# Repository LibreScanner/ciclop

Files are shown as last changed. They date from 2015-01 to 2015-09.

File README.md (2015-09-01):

# Ciclop

In this repository you will find the source files for the [bq Ciclop 3D scanner](http://diwo.bq.com/en/tag/ciclop) [[es](http://diwo.bq.com/tag/ciclop)]. Also in [thingiverse](http://www.thingiverse.com/thing:740357). If you are missing something, please do not hesitate to [file an issue on github](https://github.com/bqlabs/ciclop/issues).

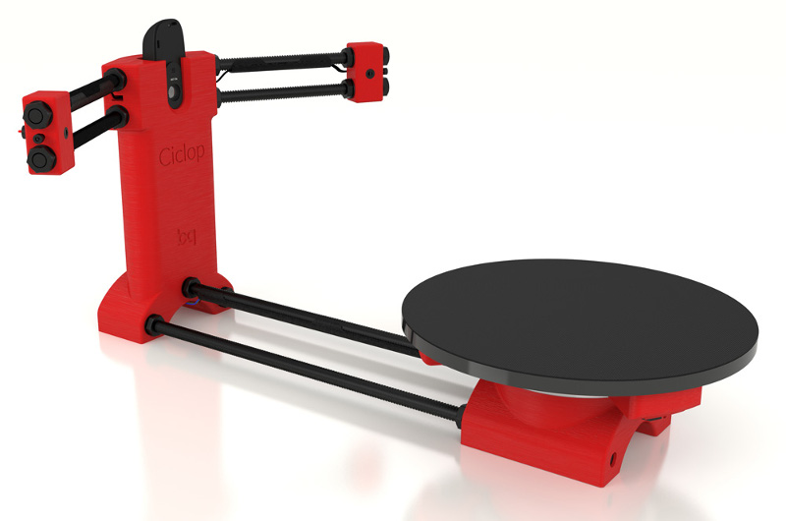
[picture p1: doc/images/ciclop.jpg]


Ciclop may be controlled by Horus software. You can find here the [firmware](https://github.com/bqlabs/horus-fw) and the [desktop application](https://github.com/bqlabs/horus).

## License 

Ciclop is licensed under a [Creative Commons Attribution-ShareAlike 4.0 International License](http://creativecommons.org/licenses/by-sa/4.0/)

Please read the LICENSE file for more details.

## Directory structure

 * `step`: The original Ciclop step files. This folder is frozen. Find the latest version in the `freecad` folder

 * `stl`: Ciclop STL files. It also contains parts with support for 3D printing

 * `dxf`: Ciclop DXF files. It contains all methacrylate pieces cutted with laser

 * `svg`: Ciclop SVG files. This folder contains all drawings for 2D printing

 * `freecad`: Ciclop source files in [FreeCAD](http://www.freecadweb.org/). This is a work in progress. All the original files are being migrated to Freecad (see below)

 * `Ciclop-BOM.ods`: Ciclop Bill of Materials. Document for [LibreOffice](https://www.libreoffice.org/)

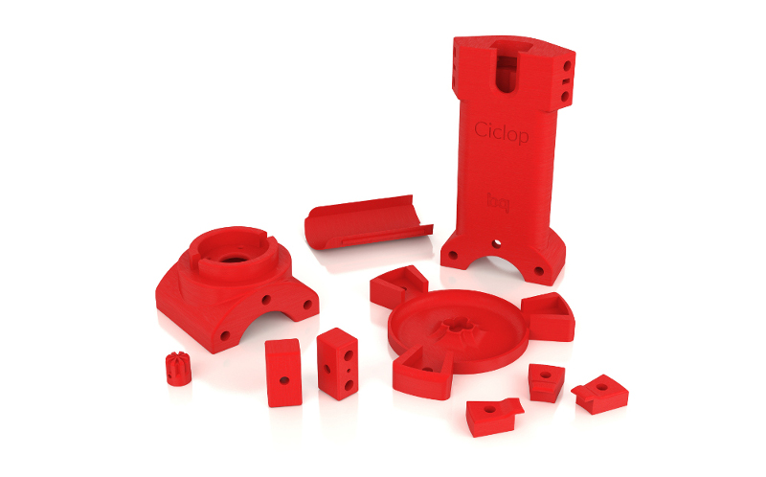
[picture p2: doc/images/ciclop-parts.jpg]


**Please note**: The original Ciclop design was made in Autodesk Inventor(tm) which is proprietary software. Since we love open formats we are migrating the Ciclop parts to [FreeCAD](http://www.freecadweb.org/), which is a multiplatform open source CAD software. We invite people from the community to join us and help us to complete the task.

[ciclop]: doc/images/ciclop.jpg
[ciclop-parts]: doc/images/ciclop-parts.jpg

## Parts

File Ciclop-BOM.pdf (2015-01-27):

Ciclop BOM

Part Number | Description | Qty | Units | Comments
G003657 | ZUM BT328 rev2 | 1 PCs
C03I050003 | USB wire 1.2m for charger | 1 PCs
C04H010020 | Stepstick Drivers A49988 4 layers (with heatsink) | 1 PCs
C05C020001 | Power supply 12V-1.5A | 1 PCs
C05I070002 | M3x10 Screw - DIN-912 Class 8.8 Black | 10 PCs
C05I070004 | M3 Nut - DIN 934 Class 8 Black | 6 PCs
C05I070032 | M8 Nut - DIN 934 Class 8 Black | 28 PCs
C05I070035 | M8 Washer - DIN-125 Class 8 Black | 18 PCs
C05I070005 | Allen key s/long 2.5 Forum | 1 PCs
C05I070068 | Bearing 16014 | 1 PCs
C05I070086 | Ceramic screw driver trimmer for electronics | 1 PCs
C05I070126 | Non-skid EPDM disk (200mm diameter) | 1 PCs
C05I070127 | HD Webcam C270 | 1 PCs
C05I070128 | MOTOR 42BYGHW609P1-X11 [Nema 17] | 1 PCs
G003527 | ZUM SCAN Shield | 1 PCs
G003803 | M8X400MM Black threaded rod | 2 PCs
G003804 | M8X292MM Black threaded rod | 1 PCs
G003805 | M8X170MM Black threaded rod | 4 PCs
G004291 | M8x30 Screw - DIN-933 Class 8.8 Black | 3 PCs
G003807 | 200x8 MM Acrylic cylinder | 1 PCs
G003810 | 3D Scanner Calibration Sticker | 1 PCs
G004066 | CICLOP 3D Scanner Methacrylate Pattern | 1 PCs
G003976 | CICLOP 3D Scanner Printed Motor Support Red | 1 PCs
G003979 | CICLOP 3D Scanner Printed Camera Support Red | 1 PCs
G003982 | CICLOP 3D Scanner Printed Electronic Cover Red | 1 PCs
G003985 | CICLOP 3D Scanner Printed Laser Support Red | 2 PCs
G003988 | CICLOP 3D Scanner Printed Fitting Motor-Disk Red | 1 PCs
G003997 | CICLOP 3D Scanner Printed Disk Support Red | 1 PCs
G004063 | CICLOP 3D Scanner Printed Pattern Support Red | 1 PCs
G004000 | CICLOP 3D Scanner Printed Clip Bearing Red | 3 PCs
G003991 | CICLOP 3D Scanner Printed Motor Cable Conduit Black | 1 PCs
G003994 | CICLOP 3D Scanner Printed Laser Cable Conduit Black | 2 PCs
| Red Line Laser, 5V, 60º, class 1, with connector | 2 PCs
G004134 | Antislip Pads Transparent H3.5mm W12.7mm | 6 PCs

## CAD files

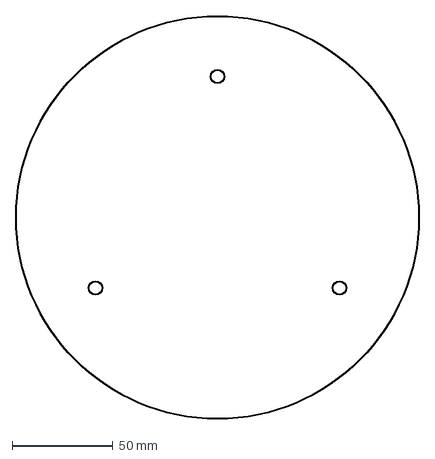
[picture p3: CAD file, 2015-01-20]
dxf/disc.dxf
200.0 x 200.0 mm

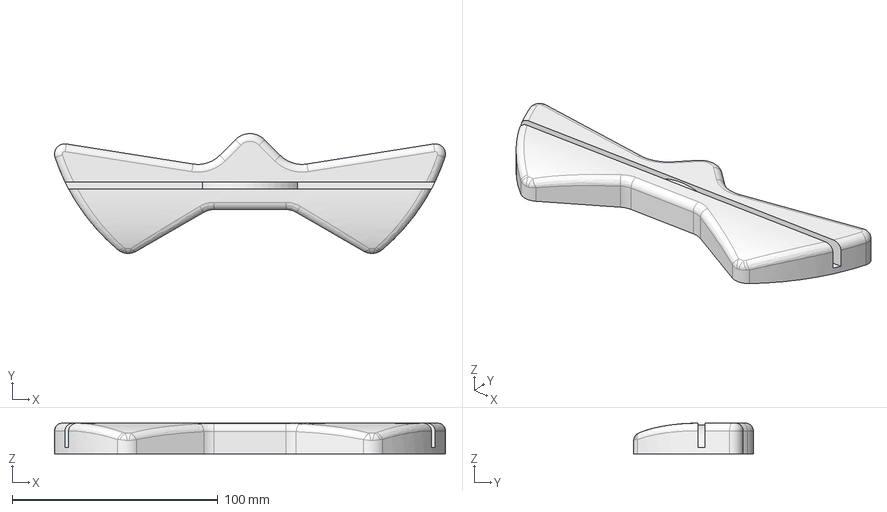
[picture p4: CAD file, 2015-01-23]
freecad/pattern-holder-v1.fcstd
190.3 x 58.3 x 15.0 mm

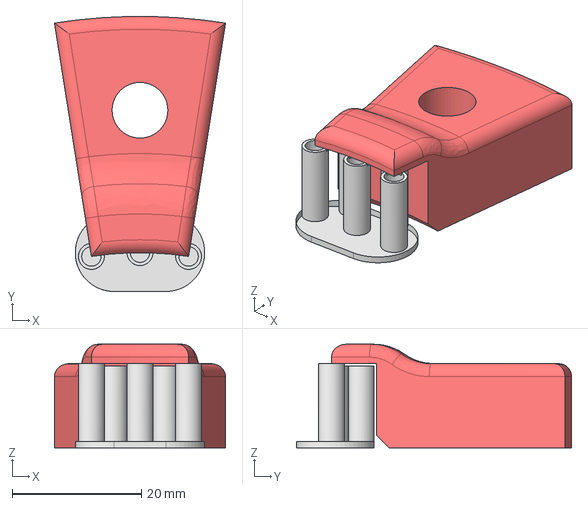
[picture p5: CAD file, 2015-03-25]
step/bearing-clip.stp
26.4 x 42.5 x 16.0 mm

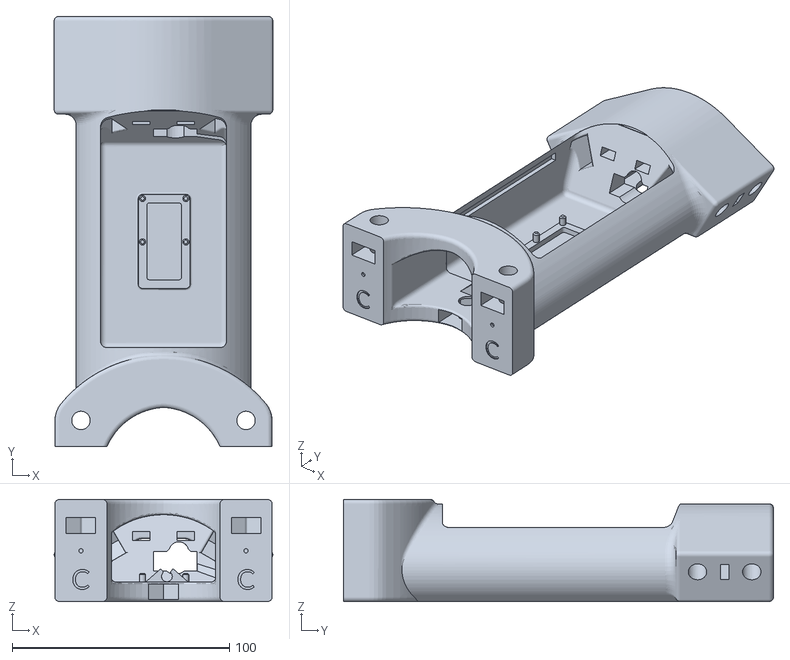
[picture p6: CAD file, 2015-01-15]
stl/camera-holder.stl
100.7 x 198.0 x 47.0

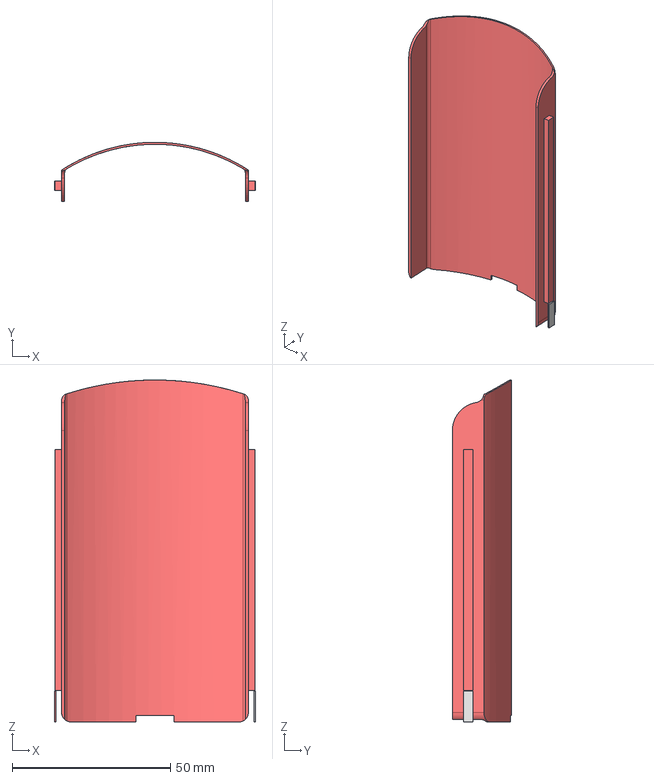
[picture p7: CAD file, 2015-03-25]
step/back-cover.stp
63.6 x 18.8 x 108.0 mm

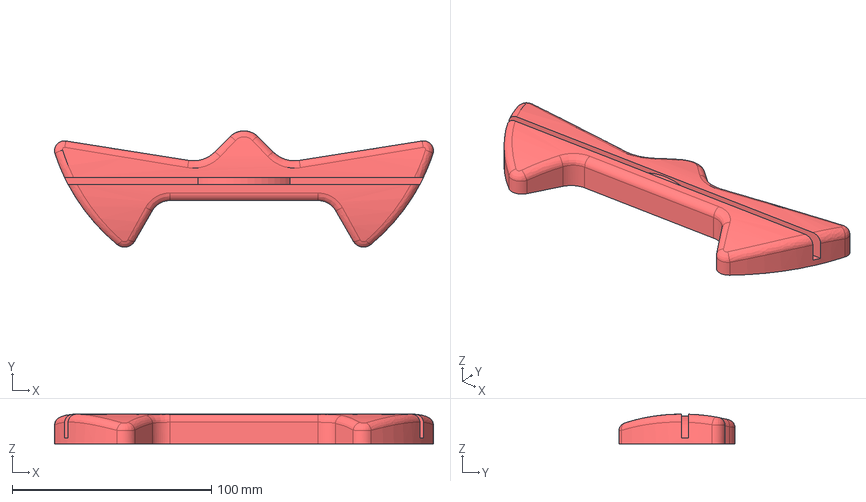
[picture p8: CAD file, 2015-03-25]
step/pattern-holder.stp
190.3 x 58.4 x 15.0 mm

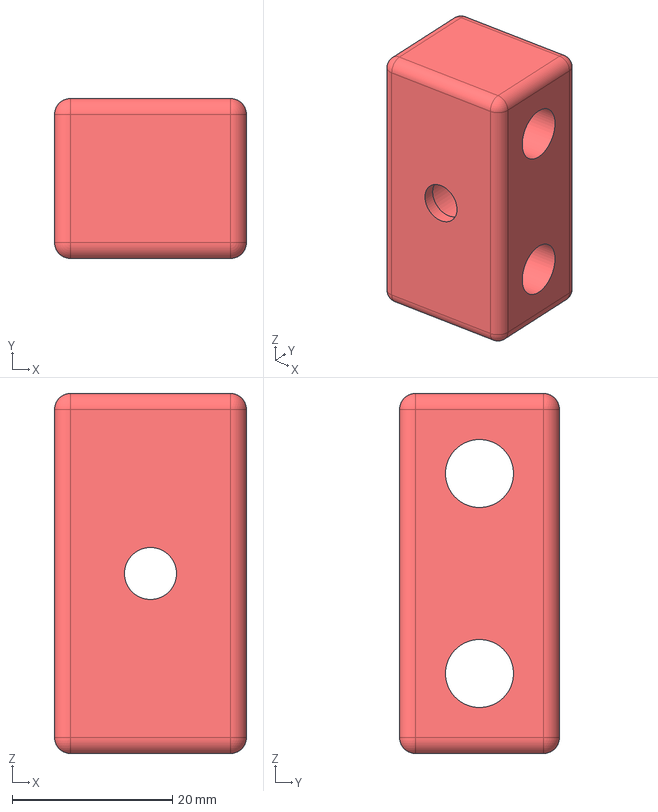
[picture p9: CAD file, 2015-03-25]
step/laser-holder.stp
24.0 x 20.0 x 45.0 mm

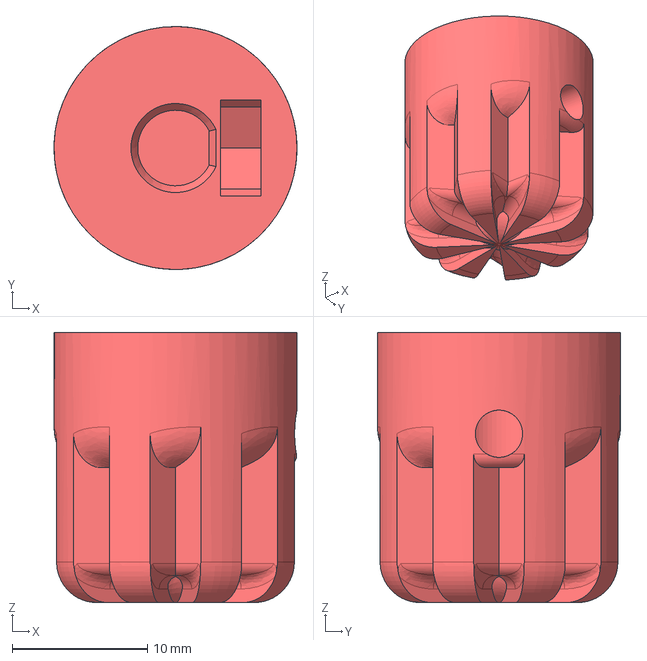
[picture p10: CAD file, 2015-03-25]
step/shaft-coupling.stp
18.0 x 18.0 x 20.0 mm

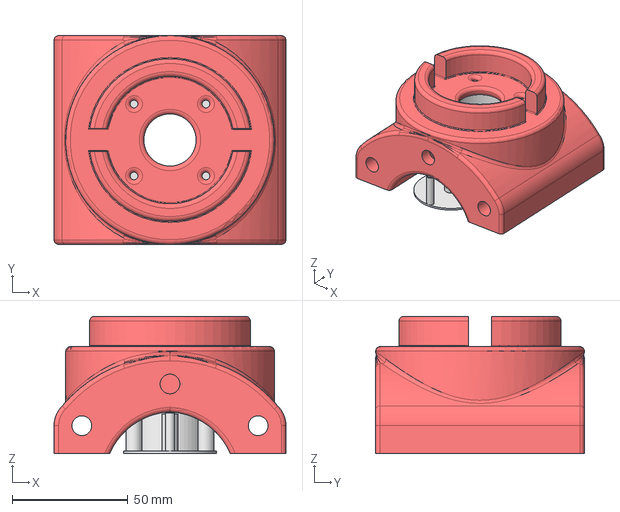
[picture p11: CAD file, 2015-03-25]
step/motor-holder.stp
100.0 x 90.0 x 59.1 mm

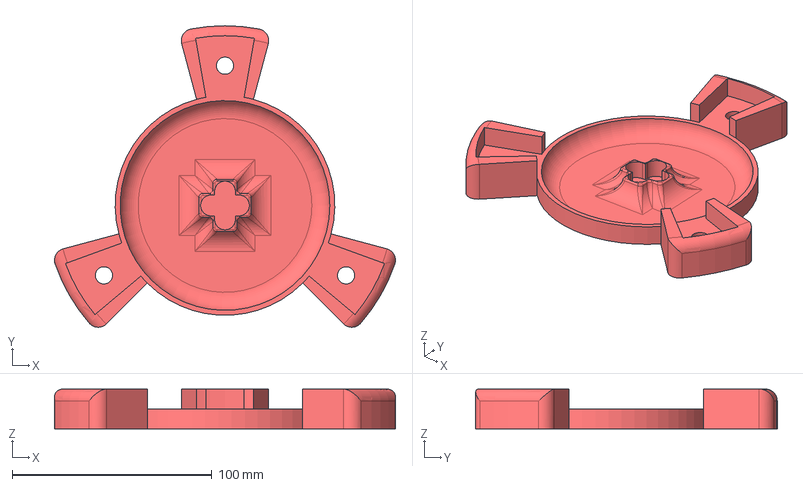
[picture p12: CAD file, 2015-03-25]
step/disc-holder.stp
170.8 x 151.0 x 20.0 mm

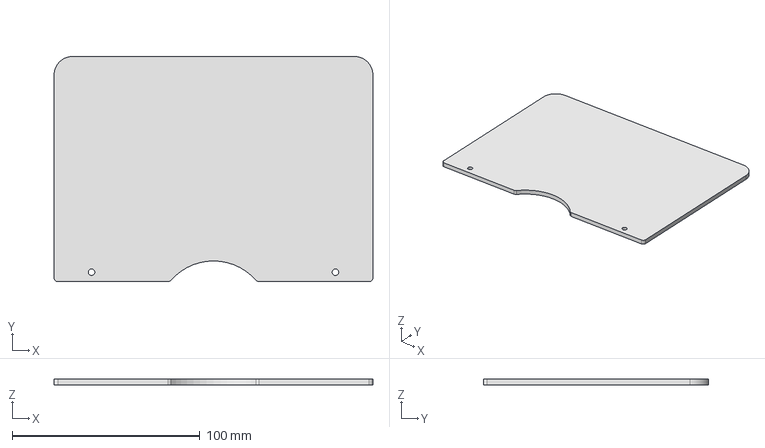
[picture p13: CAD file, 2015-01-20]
step/pattern-surface.stp
170.0 x 120.0 x 3.00 mm

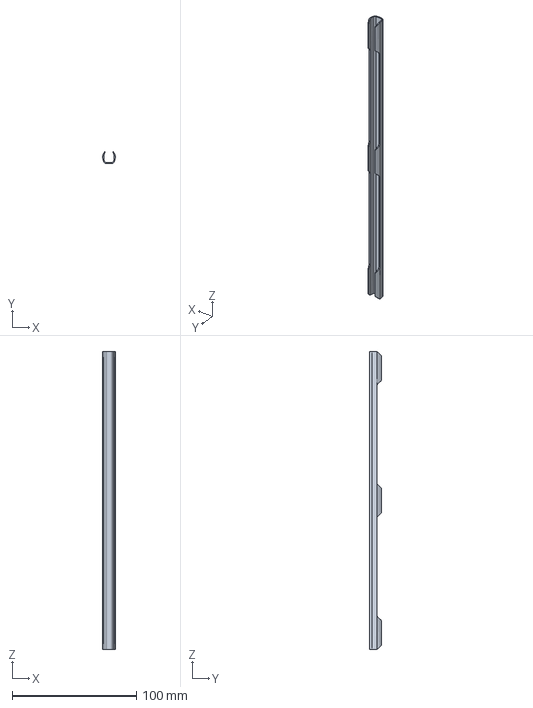
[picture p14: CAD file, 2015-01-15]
step/motor-wireway.stp
10.2 x 9.86 x 240.0 mm

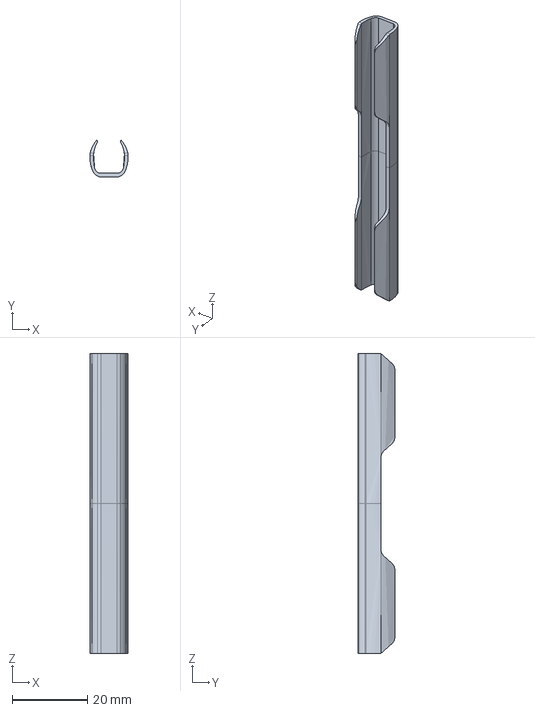
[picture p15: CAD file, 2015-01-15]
step/laser-wireway.stp
10.2 x 9.86 x 80.0 mm

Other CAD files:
dxf/pattern-surface.dxf
freecad/Shaft-coupling.fcstd
freecad/back-cover.fcstd
freecad/disc-holder.fcstd
freecad/laser-holder.fcstd
freecad/laser-wireway.fcstd
freecad/motor-holder.fcstd
freecad/motor-wireway.fcstd
stl/back-cover.stl
stl/bearing-clip.stl
stl/disc-holder.stl
stl/laser-holder.stl
stl/laser-wireway.stl
stl/motor-holder.stl
stl/motor-wireway.stl
stl/pattern-holder.stl
stl/shaft-coupling.stl

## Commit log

2015-01-15 BOM added
    [Ciclop-BOM.ods]
2015-01-15 Step files added
    [back-cover.stp, bearing-clip.stp, disc-holder.stp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]
2015-01-15 STL files added
    [back-cover-support.stl, back-cover.stl, bearing-clip-support.stl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]
2015-01-15 Step files imported to Freecad
    [back-cover.fcstd, bearing-clip.fcstd, camera-holder.fcstd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]
2015-01-20 Pattern updated
    [Ciclop-BOM.ods, pattern-holder.fcstd, pattern-holder.stl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]
2015-01-20 Disc dxf added
    [disc.dxf]
2015-01-20 Motor holder v1.0
    Part Motor-holder in FreeCAD format
    [motor-holder.fcstd]
2015-01-21 Laser-holder FreeCAD format v1.0
    Part Laser-holder migrated to FreeCAD format
    [laser-holder.fcstd]
2015-01-22 STL files updated
    [back-cover-support.stl, back-cover.stl, bearing-clip-support.stl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]
2015-01-22 Step files updated
    [bearing-clip.stp, disc-holder.stp, motor-holder.stp]
2015-01-22 Freecad files updated from Step files
    [bearing-clip.fcstd, camera-holder.fcstd, disc-holder.fcstd]
2015-01-23 part pattern-holder migrated to FreeCAD
    [pattern-holder.fcstd]
2015-01-27 Disc holder updated
    [Ciclop-BOM.ods, disc-holder.fcstd, disc-holder.stp]
2015-02-06 Pattern holder and shaft coupling updated
    [pattern-holder.stl, pattern-holder.stp, shaft-coupling.stp]
2015-03-25 Factory Step files updated
    [back-cover.stp, bearing-clip.stp, disc-holder.stp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]
2015-03-25 Freecad directory cleaned
    [back-cover.fcstd, bearing-clip.fcstd, camera-holder.fcstd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]
2015-03-25 Freecad laser holder updated
    [laser-holder.fcstd, pattern-holder-v1.fcstd]
2015-03-25 Factory STL files updated
    [back-cover.stl, disc-holder.stl, laser-wireway.stl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]
2015-05-05 Added shaft-coupling.fcstd object.
    [Shaft-coupling.fcstd]
2015-05-05 shaft-coupling: stl file deleted from assembly.
    [Shaft-coupling.fcstd]
2015-05-06 Added disc-holder.fcstd object. Not tested.
    [disc-holder.fcstd]
2015-05-07 Exported laser-wireway to .fcstd format. Not tested.
    [laser-wireway.fcstd]
2015-05-08 Fixed bug. The union between cuerpo-motivo_central works now fine in V0.16.
    [disc-holder.fcstd]
2015-05-08 Added laser-wireway.fcstd object.
    [laser-wireway.fcstd]
2015-05-08 Added motor-wireway.fcstd object.
    [motor-wireway.fcstd]
2015-05-08 Imported back-cover.stl to back-cover.fcstd
    [back-cover.fcstd]
2015-05-08 Added fillet and shell to half body.
    [back-cover.fcstd]
2015-05-11 Finished v1.0
    [back-cover.fcstd]
